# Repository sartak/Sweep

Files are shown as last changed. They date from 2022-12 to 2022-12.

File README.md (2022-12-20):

# sartak's fork of Ferris Sweep

| Front | Back |
| :---: | :---: |
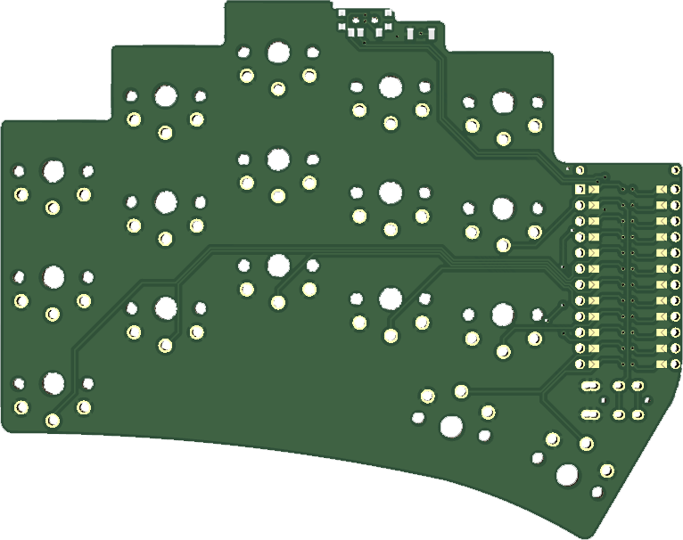
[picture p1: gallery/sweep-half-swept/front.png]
front
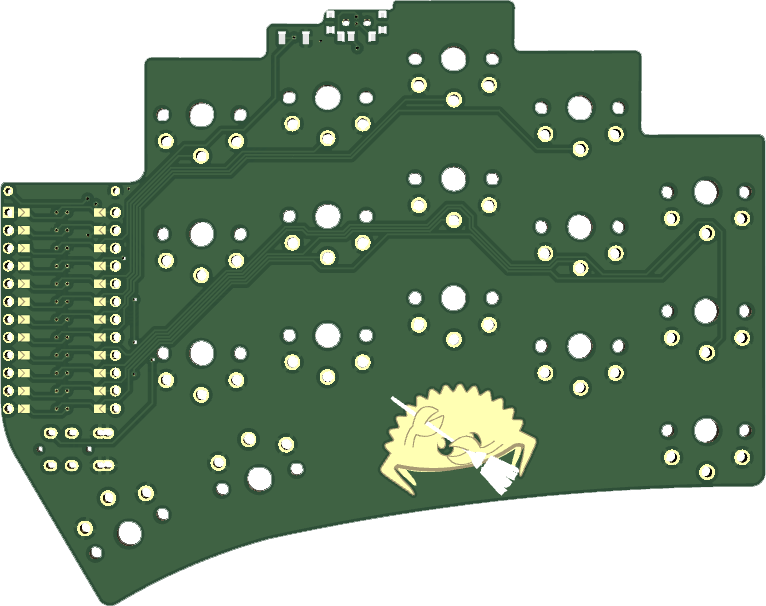
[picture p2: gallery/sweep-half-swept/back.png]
back
|  |  |

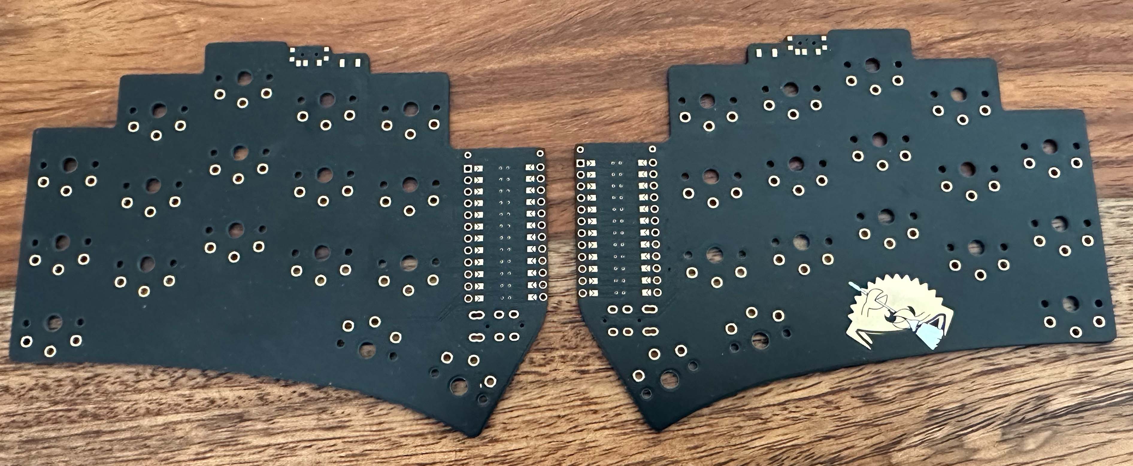
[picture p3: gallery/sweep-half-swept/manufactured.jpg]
manufactured PCB

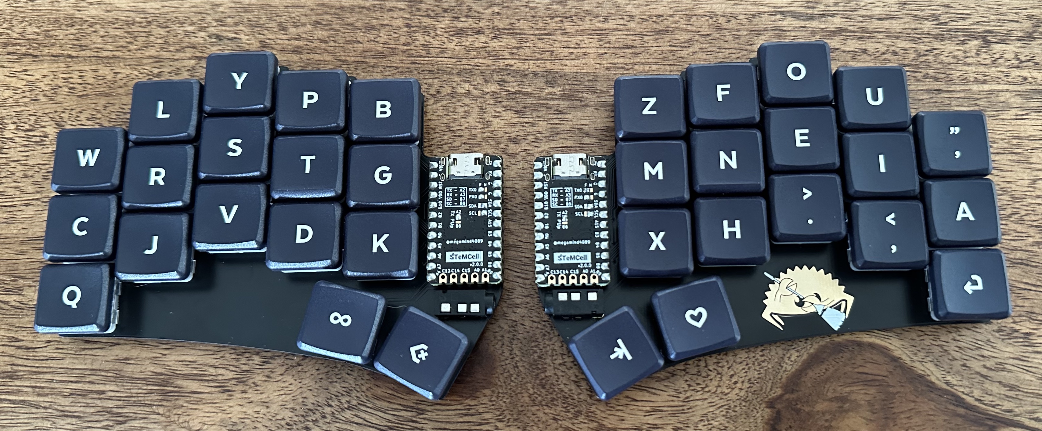
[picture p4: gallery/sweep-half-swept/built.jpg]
built keyboard


This is a fork of [Sweep](https://github.com/davidphilipbarr/Sweep) with the following modifications to the Half-Swept board:

- Removed all the silkscreen text and markings (so you better already know how to build one of these!)
- Refined the top edge to be staggered with the keys, a la [Ben Vallack](https://www.youtube.com/watch?v=JqpBKuEVinw)
- Adjusted the position of the power switch and reset button
- Removed tenting puck and holes unnecessary for Kailh choc v1 switches

The [`half-swept_gerber.zip`](https://github.com/sartak/Sweep/raw/main/Sweep%20half-swept/half-swept_gerber.zip) has been updated, ready to be sent to a PCB manufacturer.

My impressions so far:

- Tidying up the PCB feels real nice! When I'm using the keyboard, I appreciate that there are no distractions—no tenting holes peeking through keycaps, no overhang above the top row… I can't even see the power switch or reset button unless I'm above looking nearly straight down. And of course, no noisy silkscreen or superfluous holes makes the board feel more premium when inspecting the reverse sides.
- The reset button is a hair too close to the switch below it. It works, but only _just_ barely. There's a ~1 millimeter gap. Next revision will fix that.
- I've only done a wired build so far, but I'm satisfied with the multimeter testing I did for the power switch and battery, so I'm sure wireless will work.

See [https://github.com/sartak/keyboard](https://github.com/sartak/keyboard) for how I use this.

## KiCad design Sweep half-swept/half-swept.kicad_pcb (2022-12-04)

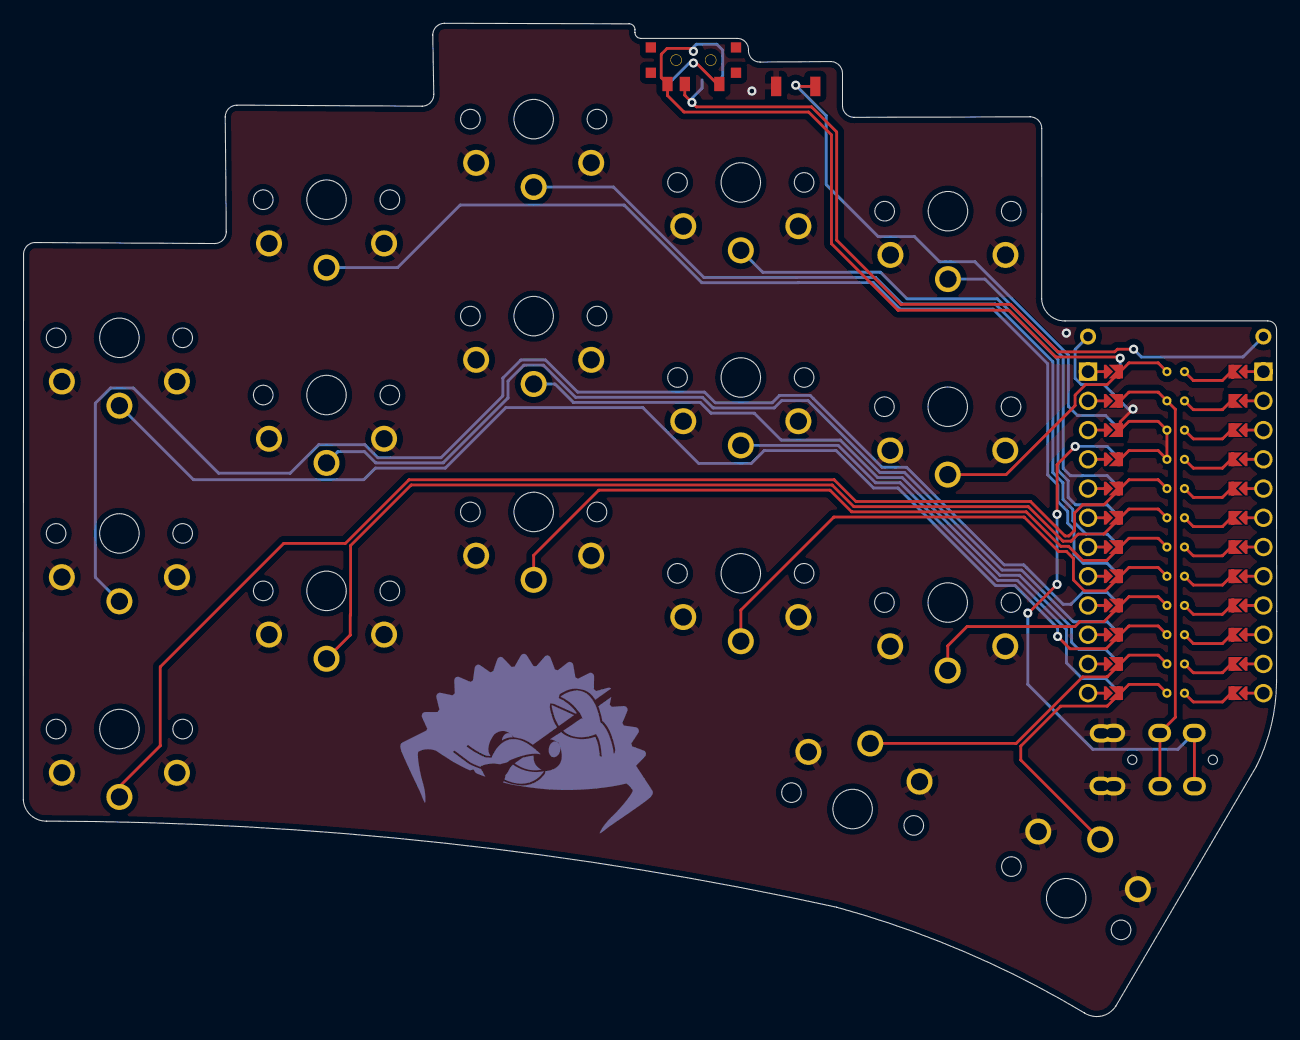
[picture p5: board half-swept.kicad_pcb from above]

Board: 2 copper layers, 108.9 x 86.3 mm, 24 parts (0 on the bottom side), 23 nets.

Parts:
 : MountingHole_Pad; 1pin_conn
 #2: MountingHole_Pad; 1pin_conn
 #3: Tenting_Puck2
 #4: SW_SPDT; SPDT_C128955
J2: AudioJack4dpb; TRRS-PJ-DPB2
RSW2: SW_Push; Tactile-Switch_SMT
SW1, SW2, SW3, SW4, SW5, SW6, SW7, SW8, SW9, SW10, SW11, SW12, SW13, SW14, SW15, SW16, SW17: SW_Push; SW_PG1350_rev_DPB
U1: ProMicro-kbd; ProMicro_jumpers_facedown

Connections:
BT+_r: .1, #4.2
Switch1: SW1.1, U1.10
Switch2: SW2.1, U1.17
Switch3: SW3.1, U1.18
Switch4: SW4.1, U1.19
Switch5: SW5.1, U1.20
Switch6: SW6.1, U1.16
Switch7: SW7.1, U1.15
Switch8: SW8.1, U1.14
Switch9: SW9.1, U1.13
Switch10: SW10.1, U1.1
Switch11: SW11.1, U1.5
Switch12: SW12.1, U1.6
Switch13: SW13.1, U1.7
Switch14: SW14.1, U1.8
Switch15: SW15.1, U1.9
Switch16: SW16.1, U1.11
Switch17: SW17.1, U1.12
Switch18: J2.R1, U1.2
gnd: #2.1, J2.S, J2.T, RSW2.1, RSW2.2, SW1.2, SW2.2, SW3.2, SW4.2, SW5.2, SW6.2, SW7.2, SW8.2, SW9.2, SW10.2, SW11.2, SW12.2, SW13.2, SW14.2, SW15.2, SW16.2, SW17.2, U1.3, U1.4, U1.23
raw: #4.3, U1.24
reset: RSW2.1, RSW2.2, U1.22
vcc: J2.R2, U1.21

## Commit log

2022-12-04 Remove tenting puck
    [half-swept.kicad_pcb]
2022-12-04 Remove text from silkscreen
    [half-swept.kicad_pcb]
2022-12-04 Remove alignment corners for switches
    [half-swept.kicad_pcb]
2022-12-04 Remove TRRS alignment lines
    [half-swept.kicad_pcb]
2022-12-04 Remove MCU alignment lines
    [half-swept.kicad_pcb]
2022-12-04 Remove battery alignment lines
    [half-swept.kicad_pcb]
2022-12-04 Remove reset alignment lines
    [half-swept.kicad_pcb]
2022-12-04 Move the reset and power switches
    [half-swept.kicad_pcb]
2022-12-04 Remove unnecessary through-holes from switches
    [half-swept.kicad_pcb]
2022-12-04 Pull in the edge cut
    [half-swept.kicad_pcb]
2022-12-04 Tweak reset trace
    [half-swept.kicad_pcb]
2022-12-04 Regenerate gerber
2022-12-04 Remove other boards and files
    [ferris-sweep-compact.kicad_pcb, ferris-sweep-compact.sch, sweep-bling-mx__bottom.kicad_pcb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]
2022-12-04 Tweaks to satisfy the Design Rules Checker
    [half-swept.kicad_pcb]
